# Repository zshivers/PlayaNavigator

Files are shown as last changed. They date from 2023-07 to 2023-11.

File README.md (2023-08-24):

# Install dependencies
- `brew install npm websocat`
- `cd test/interactive_map; npm install`
- `cd generated; npm install`

# Running Interactive Map Test
1. Compile for `host` target.
2. `npm start` - Starts the webserver with the map.
3. Go to http://localhost:5173
4. Run the host version, and pipe the websocket data into it - `websocat -s 9998 | ./.pio/build/host/program`

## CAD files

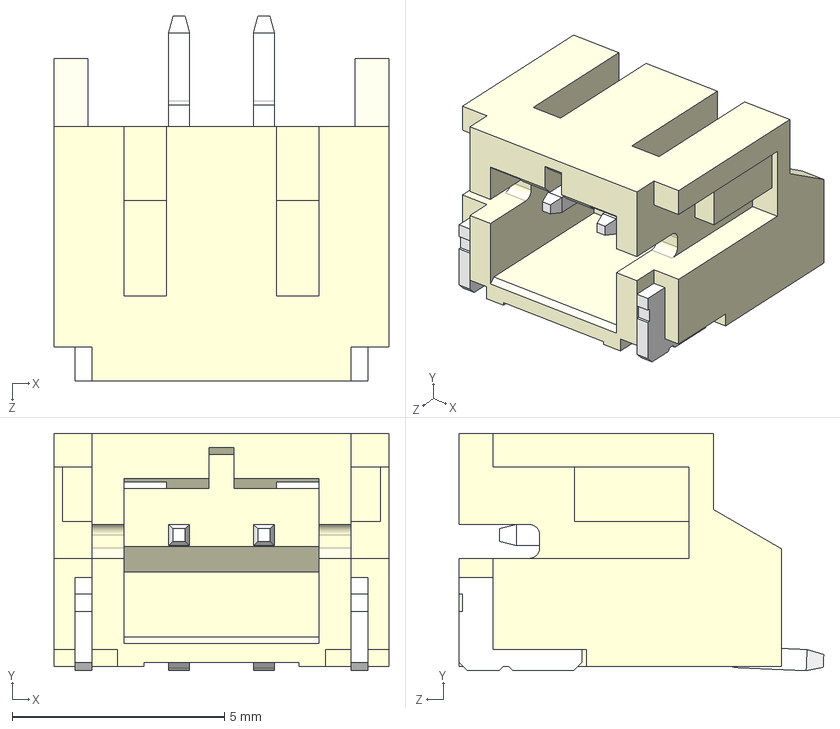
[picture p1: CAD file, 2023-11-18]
hardware/pcb/parts/S2B-PH-SM4-TB/S2B-PH-SM4-TB.step
7.90 x 5.60 x 8.60 mm

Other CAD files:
hardware/3d/PlayaNavigatorBikeMount.f3d

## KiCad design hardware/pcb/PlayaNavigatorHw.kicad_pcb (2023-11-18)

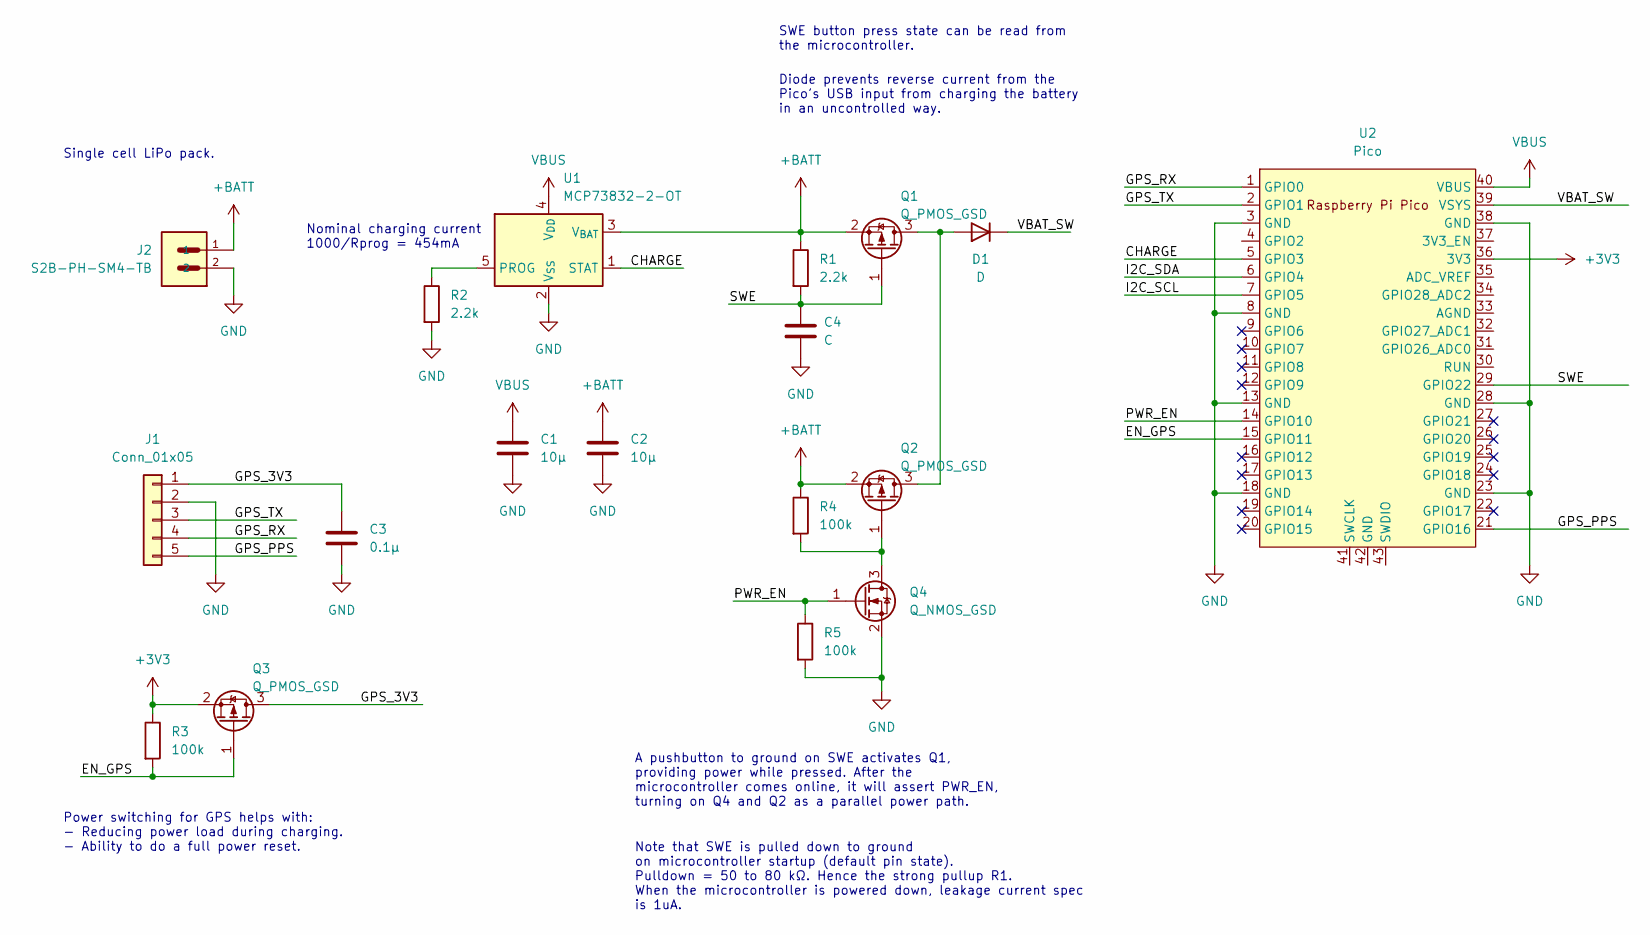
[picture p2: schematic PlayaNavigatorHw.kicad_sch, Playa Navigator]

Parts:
C1, C2: 10µ; C_1206_3216Metric
C3: 0.1µ; C_0805_2012Metric
C4: C; C_0805_2012Metric
D1: D; Nexperia_CFP3_SOD-123W
J1: Conn_01x05; PinHeader_1x05_P2.54mm_Vertical
J2: S2B-PH-SM4-TB; JST_S2B-PH-SM4-TB
Q1, Q2, Q3: Q_PMOS_GSD; SOT-23-3
Q4: Q_NMOS_GSD; SOT-23-3
R1, R2: 2.2k; C_0603_1608Metric
R3, R4, R5: 100k; C_0603_1608Metric
U1: MCP73832-2-OT; SOT-23-5; Digikey Part Number MCP73832-2ACI/MC-ND
U2: Pico; RPi_Pico_SMD_TH_Customized

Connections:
+3V3: Q3.2 (S), R3.1, U2.36 (3V3)
+BATT: C2.1, J2.1, Q1.2 (S), Q2.2 (S), R1.1, R4.1, U1.3 (V_{BAT})
/CHARGE: U1.1 (STAT), U2.5 (GPIO3)
/EN_GPS: Q3.1 (G), R3.2, U2.15 (GPIO11)
/GPS_3V3: C3.1, J1.1, Q3.3 (D)
/GPS_PPS: J1.5, U2.21 (GPIO16)
/GPS_RX: J1.4, U2.1 (GPIO0)
/GPS_TX: J1.3, U2.2 (GPIO1)
/I2C_SCL: U2.7 (GPIO5)
/I2C_SDA: U2.6 (GPIO4)
/PWR_EN: Q4.1 (G), R5.1, U2.14 (GPIO10)
/SWE: C4.1, Q1.1 (G), R1.2, U2.29 (GPIO22)
/VBAT_SW: D1.1 (K), U2.39 (VSYS)
GND: C1.2, C2.2, C3.2, C4.2, J1.2, J2.2, Q4.2 (S), R2.2, R5.2, U1.2 (V_{SS}), U2.3 (GND), U2.8 (GND), U2.13 (GND), U2.18 (GND), U2.23 (GND), U2.28 (GND), U2.38 (GND)
unnamed: D1.2 (A), Q1.3 (D), Q2.3 (D)
unnamed: Q2.1 (G), Q4.3 (D), R4.2
unnamed: R2.1, U1.5 (PROG)
VBUS: C1.1, U1.4 (V_{DD}), U2.40 (VBUS)

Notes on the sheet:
Diode prevents reverse current from the Pico's USB input from charging the battery in an uncontrolled way.
Note that SWE is pulled down to ground on microcontroller startup (default pin state). Pulldown = 50 to 80 kΩ. Hence the strong pullup R1. When the microcontroller is powered down, leakage current spec is 1uA.
Nominal charging current 1000/Rprog = 454mA
A pushbutton to ground on SWE activates Q1, providing power while pressed. After the microcontroller comes online, it will assert PWR_EN, turning on Q4 and Q2 as a parallel power path.
Power switching for GPS helps with: - Reducing power load during charging. - Ability to do a full power reset.
Single cell LiPo pack.
SWE button press state can be read from the microcontroller.

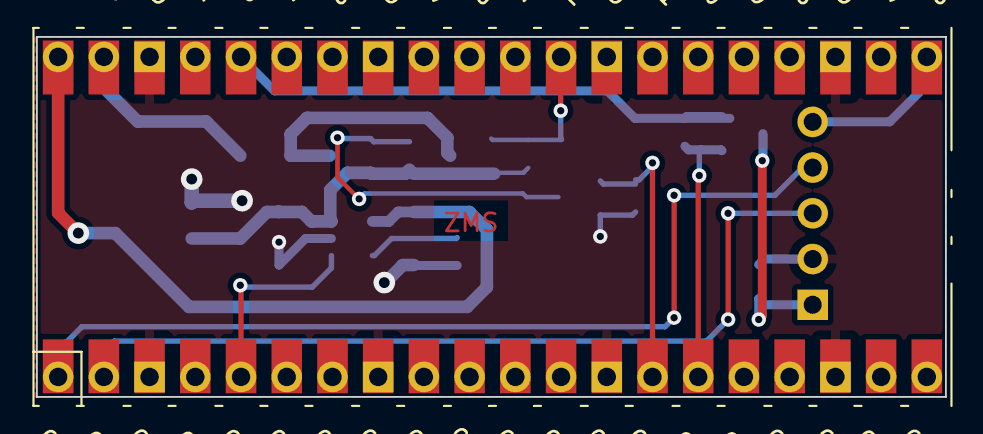
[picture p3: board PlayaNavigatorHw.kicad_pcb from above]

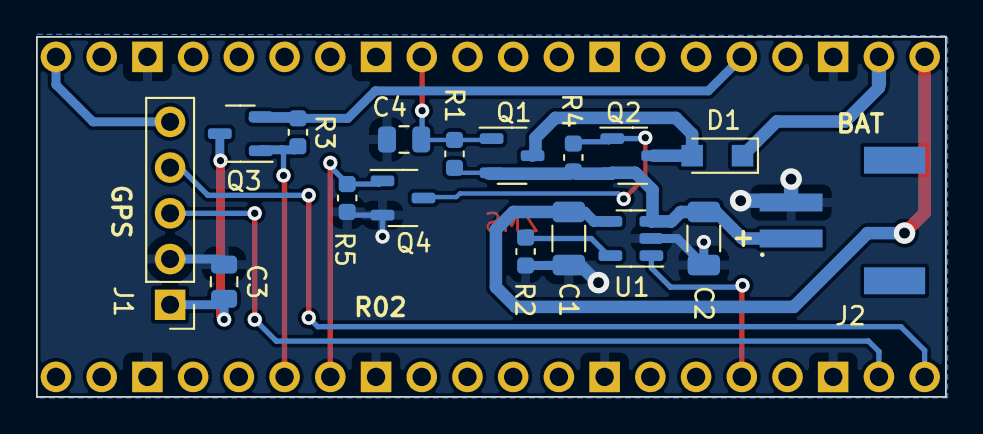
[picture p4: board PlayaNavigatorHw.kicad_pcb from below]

Board: 2 copper layers, 50.5 x 20.0 mm, 18 parts (17 on the bottom side), 16 nets.

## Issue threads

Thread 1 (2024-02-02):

Add license information

vazhnov, 2024-02-02:
Hello!

I found this project from https://hackaday.com/2024/02/01/navigate-burning-man-with-ease-with-this-custom-tool/

Could you please add information about the license of this repository — is it allowed to copy, change and use the code and PCB hardware files in any purpose?
It would be great to see any popular open source license.

zshivers, 2024-02-02:
Thanks for the reminder! Added an MIT license.

vazhnov, 2024-02-02:
MIT license — amazing! Thank you!!!

Closed 2024-02-02.

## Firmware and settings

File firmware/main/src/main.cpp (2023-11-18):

#include "OneButton.h"
#include "app_hal.h"
#include "backlight.h"
#include "board.h"
#include "gps.h"
#include "hal_time.h"
#include "lvgl.h"
#include "maybe_valid.h"
#include "power.h"
#include "ui.h"
#include "usb_storage.h"
#include "waypoint_storage.h"

Ui* ui;
Gps gps;
Power power;
Backlight backlight(kBacklightWhitePin, kBacklightRedPin, kBacklightGreenPin,
                    kBacklightBluePin);
UsbStorage usb_storage;
OneButton button_a(kButtonAPin);
OneButton button_b(kButtonBPin);
OneButton button_c(kButtonCPin);
OneButton button_d(kButtonDPin);
OneButton button_e(kButtonEPin);

void button_a_press_cb() { ui->ButtonPress(Ui::Button::kA); }
void button_b_press_cb() { ui->ButtonPress(Ui::Button::kB); }
void button_c_press_cb() { ui->ButtonPress(Ui::Button::kC); }
void button_d_press_cb() { ui->ButtonPress(Ui::Button::kD); }
void button_e_press_cb() { ui->ButtonPress(Ui::Button::kE); }

void button_a_long_press_cb() { ui->ButtonLongPress(Ui::Button::kA); }
void button_b_long_press_cb() { ui->ButtonLongPress(Ui::Button::kB); }
void button_c_long_press_cb() { ui->ButtonLongPress(Ui::Button::kC); }
void button_d_long_press_cb() { ui->ButtonLongPress(Ui::Button::kD); }
void button_e_long_press_cb() { ui->ButtonLongPress(Ui::Button::kE); }

void setup() {
  power.Start();

  // Since the pushbutton for power will only keep the power on until the user
  // releases it, the first thing to do on boot is to take over control to keep
  // power on.
  power.power_enable(true);

  power.gps_enable(true);

  hal_setup();

  usb_storage.Start();
  backlight.Start();
  backlight.SetColor(1.0, 0, 0, 0);

  ui = new Ui(usb_storage.GetPlayaMapConfig(), usb_storage.GetBathrooms(),
              power, backlight);

  gps.Start();

  button_a.attachClick(button_a_press_cb);
  button_b.attachClick(button_b_press_cb);
  button_c.attachClick(button_c_press_cb);
  button_d.attachClick(button_d_press_cb);
  button_e.attachClick(button_e_press_cb);

  button_a.attachLongPressStart(button_a_long_press_cb);
  button_b.attachLongPressStart(button_b_long_press_cb);
  button_c.attachLongPressStart(button_c_long_press_cb);
  button_d.attachLongPressStart(button_d_long_press_cb);
  button_e.attachLongPressStart(button_e_long_press_cb);
}

void loop() {
  hal_loop();

  button_a.tick();
  button_b.tick();
  button_c.tick();
  button_d.tick();
  button_e.tick();

  const uint32_t ms = time_millis();
  gps.Update(ms);

  ui->OnGpsInfo(gps.gps_info());
  ui->update(ms);
}

#ifdef PLATFORM_NATIVE
int main(void) {
  setup();
  while (true) {
    loop();
  }
}
#endif

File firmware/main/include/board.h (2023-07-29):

#pragma once

constexpr int kPicoLedPin = 25;

constexpr int kButtonAPin = 12;
constexpr int kButtonBPin = 13;
constexpr int kButtonCPin = 14;
constexpr int kButtonDPin = 15;
constexpr int kButtonEPin = 22;

constexpr int kDisplayCsPin = 17;
constexpr int kDisplaySckPin = 18;
constexpr int kDisplayMosiPin = 19;
constexpr int kDisplayDcPin = 20;
constexpr int kDisplayResetPin = 21;

constexpr int kBacklightRedPin = 6;
constexpr int kBacklightGreenPin = 7;
constexpr int kBacklightBluePin = 8;
constexpr int kBacklightWhitePin = 9;

constexpr int kGpsUartTxPin = 0;
constexpr int kGpsUartRxPin = 1;

constexpr int kVSysAdcInputPin = 29;
constexpr int kPowerEnablePin = 10;
constexpr int kGpsEnablePin = 11;
constexpr int kGpsPpsPin = 16;
constexpr int kChargingPin = 3;
constexpr int kUsbPluggedPin = 24;

constexpr int kSystemClockFreqHz = 48'000'000;

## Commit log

2023-05-23 - Build targets for pico and native - Adapted driver for ST7567 - Abstraction for UI
2023-07-16 Fixed issues with coordinates library, more work on automatic shutdown.
    [gps.cpp, main.cpp, power.cpp]
2023-07-27 Bug fix for PPS input, removed button class, updated playa config with coordinates released for 2023.
    [app_hal.cpp, board.h, gps.cpp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]
2023-07-30 Added temperature measurement
2023-07-30 Add temperature sensing
2023-08-14 Revert host GPS to using keyboard input.
    [gps.cpp]
2023-08-24 Use the watchdog timer.
2023-11-18 Add PCB design files
    [PlayaNavigatorHw.kicad_pcb, PlayaNavigatorHw.kicad_sch, S2B-PH-SM4-TB.step]
2023-11-18 Add Fusion360 files
    [PlayaNavigatorBikeMount.f3d]
